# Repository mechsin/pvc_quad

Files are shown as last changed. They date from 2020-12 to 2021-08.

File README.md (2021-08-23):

# PVC Quadcopter

These are open SCAD files for a custom quadcopter that uses 1 inch PVC pipe and fittings for some of the construction. Original inspiration for the build was taken from this [instructables](https://www.instructables.com/The-Ultimate-PVC-Quadcopter/). My original design started off very similar to the build in the link however as can be seen from the pictures below my design has evolved quite a bit. The primary changes have been to augment or replace parts with 3d printed ones. At the moment the motor mounts and landing struts are 3d printed as a single piece. The I also have now added 3d printed mounts for the flight controller and power break out board. 

This is really just a personal project I don't intend to update this repo with full build notes. If would like to use any of the parts feel free to. 

The can all be printed with out supports. I use an Anet A8 to print them so you don't need a precision machine. I primary print in PLA or PLA+ my pieces break frequently but usually after a crash that I think would warrant it, I am not a great pilot :).

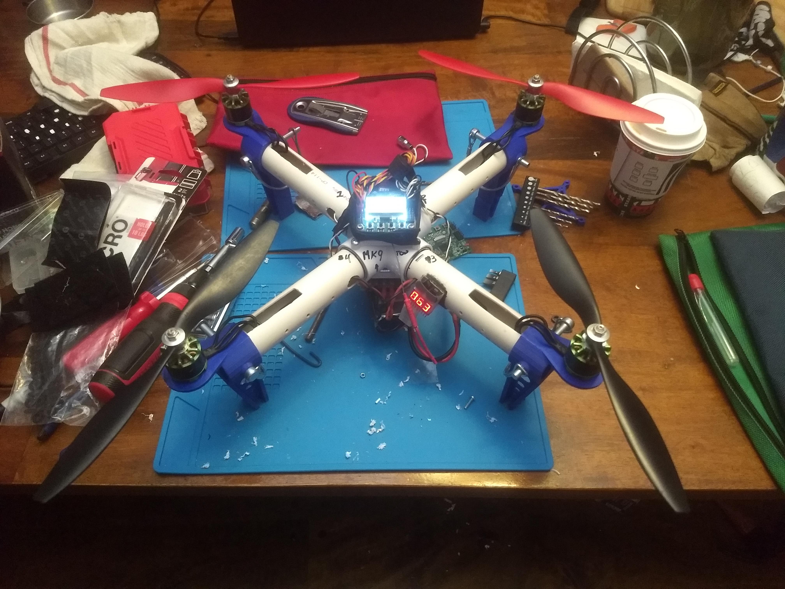
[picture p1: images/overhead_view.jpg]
Quad overview powered up and tools Quad over head view


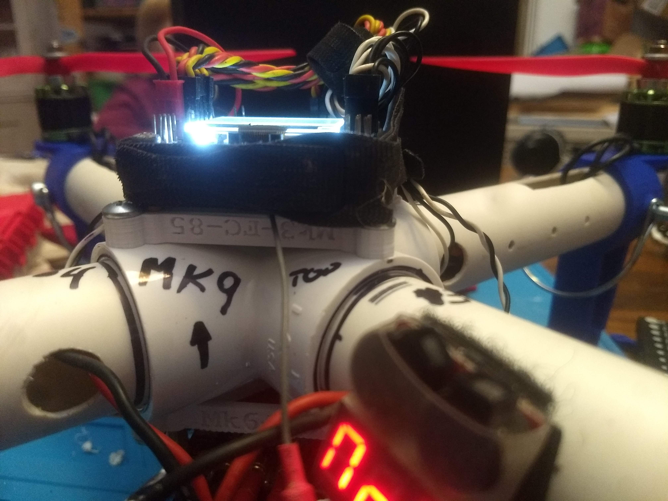
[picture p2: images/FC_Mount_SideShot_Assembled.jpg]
Flight controller mount up close FC Mount Side Shot


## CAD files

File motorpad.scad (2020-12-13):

use <quadparts.scad>;
use <pvcadapter.scad>;
use <landingstrut.scad>;

module pad_projection(baseWidth, padWidth, padLength, extra){

outerdiameter = padLength;
basewidth = baseWidth;

outerradius = outerdiameter / 2;
CS = sqrt (pow (outerradius + extra, 2) + pow (basewidth / 2, 2));
T = sqrt (pow (outerradius + extra, 2) + pow (basewidth / 2, 2) - pow(outerradius, 2));
phi = 180 - asin (outerradius / CS) - acos (basewidth / (2 * CS));

points =[[basewidth / 2, 0],
[basewidth / 2 + T * cos (phi), T * sin (phi)],
[-basewidth / 2 - T * cos (phi), T * sin (phi)],[-basewidth / 2, 0]];

resize([padWidth, padLength + extra])
union ()
{
polygon (points = points);
translate ([0, outerradius + extra])
circle (d = outerdiameter);
};
};

module padShaped(){
// This most outer difference removes all the extra material and shapes the piece as we want it
difference(){

// This initial difference on the pad makes the cut outs for the motor screw holes and makes the cutout
// for the motor cross pad that will eventually be added
difference(){
linear_extrude (height = height, center = false)
pad_projection(baseWidth, padWidth, padLength, extra=strech);

//Motor mount screw holes and cross pad
zMountCross = motorDepth;
translate([0, strech + padLength / 2, zMountCross])
rotate(-45)
mountCrossDiff(screwDiameter, mountDiameter, screwLength=height, motorDepth=motorDepth, extra=padThickness, centerHoleDiameter=centerHoleDiameter);
};


// Center cut out
// This creates the cylinder that makes the arc underneath the pad
cyWidth = padWidth + 5;
translate([0, totalLength, subHeight / 2])
union(){
resize([cyWidth, padLength * 2, subHeight])
rotate(90, v=[0, 0 ,1])
rotate(90, v=[1, 0, 0])
cylinder(cyWidth, r=padLength,center=true);
translate([-cyWidth / 2, -padLength, -subHeight / 2])
cube([cyWidth, padLength, subHeight / 2], center=false);
};

// Two cylinders to remove the material from the sides of the platform and create the I beam shape in the
// center
translate([padWidth / 2, totalLength, subHeight / 2])
resize([sideDiameter, totalLength, subHeight])
rotate(90, v=[1,0,0])
cylinder(h=totalLength, d=subHeight);

translate([-padWidth / 2, totalLength, subHeight / 2])
resize([sideDiameter, totalLength, subHeight])
rotate(90, v=[1,0,0])
cylinder(h=totalLength, d=subHeight);

// This is a cube that is used to remove excess material from the bottom of the model. There is
// a circular cut out in the top middle of it in order to leave the I beam shape
difference(){
translate([-padWidth / 2, 0, 0])
cube([padWidth, totalLength, height / 2]);

translate([0, totalLength, height / 2])
rotate(90,v=[1,0,0])
cylinder(h=totalLength, d=adapterInnerDiameter);
};
};
}

// Define all sizes having to do with the motor pad itself
//padLength = 45;
//padWidth = 53;
padLength = 38;
padWidth = 38;
padThickness = 4;
baseWidth = 20;
strech = 10;
totalLength = padLength + strech;
height = 42;
subHeight = height - padThickness;

// Define all measurements for the PVC adapter
adapterInnerDiameter = 34;
adapterOuterDiameter = 42;
adapterLength = strech + 20;
holeDepth = adapterLength;

//PVC adapter side mount holes
shScrewDiameter = 6.1;
shPadDiameter = 9;
shPadWidth = 1.5;
shChamferAngle = 45;

// Mark Text parameters
markText = "Mk5";
textHeight = 1.5;
markXTrans = -(baseWidth / 2 - 1);
markYTrans = -(adapterLength - strech - 1);


// These control the width of the I beam shape in that can be seen in the center of the
// hole for the PVC adapter
centerBarWidth = 5;
sideDiameter = padWidth - centerBarWidth;

// Measurements used to create the screw holes for mounting the motor.
screwDiameter = 3;
mountDiameter = 8;
screwLength = 12;
motorDepth = 3;
centerHoleDiameter = 8;

// Land strut measurements
strutLength = baseWidth;
strutWidthInitial = adapterLength;
strutWidthFinal = 15;
strutHeight = 70;




translate([0, 0, height])
rotate(180, v=[0,1,0])

union(){

padShaped();

// Add the motor mount cross pad for the screws
zMountCross = height - (screwLength - motorDepth);
translate([0, strech + padLength / 2, zMountCross])
rotate(-45)
mountCross(screwDiameter, mountDiameter, screwLength, motorDepth, extra=padThickness, centerHoleDiameter=centerHoleDiameter);



translate([0, strech, height / 2])
rotate(180, [0, 1, 0])
// Merge PVC Adapter and landing strut together
union() {
translate([-baseWidth / 2,-adapterLength,adapterOuterDiameter / 2])
landingStrut(strutLength, strutWidthInitial, strutWidthFinal, strutHeight, webCircles=true);
rotate(90, v=[1, 0, 0])
pvc_adapter(innerdiameter=adapterInnerDiameter,outerdiameter=adapterOuterDiameter,basewidth=baseWidth,extra=0,height=adapterLength, numberflats=2, sideholes=true, shpadwidth=shPadWidth, shpaddiameter=shPadDiameter, shscrewdiameter=shScrewDiameter, shchamferangle=shChamferAngle);
}


};

// Add Version text
//translate([markXTrans, markYTrans, height])
//linear_extrude(height=textHeight, center=false)
//text(markText, valign="bottom", halign="left", size=3);

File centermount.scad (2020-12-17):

module
hexagon (d, height)
// D is the distance between two oppisite vertices on the hexagon
// d is the distance between two parallel sides
{
   D = d * 2 / sqrt(3);
   t = D / 2;

   translate([0, 0, height / 2])
   union() {
   for (r =[0, 60, 120]) {
     rotate ([0, 0, r]) cube ([t, d, height], true);
   }
}
}


module
centerBoardMount(beamLength, beamWidth, beamHeight, hole2holeX, hole2holeY, boardDiameter, boardHoleDiameter, boardNutDiameter, boardNutDepth, mountDiameter, mountHoleDiameter, mountOffSet, braceOffset=0, braceWidth=0, centerHole=true)
{

// This translate list is use to create the holes for the board
// mount they are multiplid by diagonal distane between the
// board mounting holes as well as the diagonal for the mounting
// holes for the bracket it self
translateList = [
                     [1, 0, 0]
                    ,[0, 1, 0]
                    ,[-1, 0]
                    ,[0, -1, 0]
                  ];

diagonalBoard = sqrt(pow(hole2holeX, 2) + pow(hole2holeY, 2));
diagonalMount = beamLength - mountDiameter - 2 * mountOffset;
translateBoard = diagonalBoard/ 2 * translateList;
translateMount = concat(diagonalMount / 2 * translateList, [[0,0,0]]);

// Brace Dimensions
braceWidth = braceWidth ? braceWidth : beamWidth;

// After the part is constructed we flip it over and put it in the
// positive Z space. This is so the inserts for the nuts will be
// printed up.
translate([0,0, beamHeight])
rotate(180, v=[1, 0, 0])

// Subtract the holes in the mounts and the pocket for the nuts
difference() {

// Union all the arms, bracket and board mounts
union() {

   // Create the mounts for the board
   for (entry = translateBoard) {
      translate(entry)
      difference() {
         cylinder(d=boardDiameter, h=beamHeight);
      }
   }

  // Create the mounts for the bracket
  for (entry = translateMount) {
      translate(entry)
      cylinder(d=mountDiameter, h=beamHeight);
   }

   // Create on arm of the bracket
   translate([-beamWidth / 2, -beamLength / 2, 0])
   cube([beamWidth, beamLength, beamHeight]);

   // Create the other arm of the bracket
   rotate(-90)
   translate([-beamWidth / 2, -beamLength / 2, 0])
   cube([beamWidth, beamLength, beamHeight]);

   // Add braces if brace offset was provided
   if (braceOffset) {
      braceLength = sqrt(pow(braceOffset, 2) + pow(braceOffset, 2));
      bracePoints = [
                     [braceOffset, 0]
                     , [braceOffset + braceWidth / sin(45), 0]
                     , [0, braceOffset + braceWidth / sin(45)]
                     , [0, braceOffset]
                    ];
      for (rv = [0:90:270]) {
         rotate(rv, v=[0, 0, 1])
         linear_extrude(beamHeight)
         polygon(bracePoints);
      }
   }
};

// Create the holes for the board in the mounts and
// the pocket for the nuts
for (entry = translateBoard) {
      translate(entry)
      union() {
         cylinder(d=boardHoleDiameter, h=beamHeight, $fn=20);
         hexagon(boardNutDiameter, boardNutDepth);
      }

      }

// Create the holes for the bracke mount
for (entry = translateMount) {
      translate(entry)
      cylinder(d=mountHoleDiameter, h=beamHeight, $fn=20);
   }

};

}

//TEST

//// Board dimensions
//hole2holeX = 46;
//hole2holeY = 45;
//
//boardDiameter = 5 * 2 / sqrt(3) + 3;
//boardHoleDiameter = 2.8;
//boardNutDiameter = 5;
//boardNutDepth = 3.5;
//
//// Beam dimensions
//beamLength = 99;
//beamWidth = boardHoleDiameter;
//beamHeight = 7;
//
//// Mount hole dimensions
//mountDiameter = 8;
//mountHoleDiameter = 4.5;
//mountOffset = 2;
//
//// Brace
//braceOffset = sqrt(pow(hole2holeX, 2) + pow(hole2holeY, 2)) / 2;
//
//
//centerBoardMount(beamLength, beamWidth, beamHeight, hole2holeX, hole2holeY, boardDiameter, boardHoleDiameter, boardNutDiameter, boardNutDepth, mountDiameter, mountHoleDiameter, mountOffset, braceOffset=braceOffset, centerHole=true);

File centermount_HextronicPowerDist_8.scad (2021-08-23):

include<centermount.scad>


// Dimensions for the PCB
// X and Y offsets for the mounting holes for the PCB
offsetX = 45;
offsetY = 44;

boardDiameter = 5 * 2 / sqrt(3) + 3;
boardHoleDiameter = 2.8;
boardNutDiameter = 5.2;
boardNutDepth = 3.5;

// Beam Dimensions

beamLength = 85;
beamWidth = boardHoleDiameter;
beamHeight = 7;

// Mount hole dimensions
mountDiameter = 8;
mountHoleDiameter = 4.5;
mountOffset = 0;

// Brace
braceOffset = sqrt(pow(offsetX, 2) + pow(offsetY, 2)) / 2;

difference(){

centerBoardMount(beamLength, beamWidth, beamHeight, offsetX, offsetY, boardDiameter, boardHoleDiameter, boardNutDiameter, boardNutDepth, mountDiameter, mountHoleDiameter, mountOffset, braceOffset=braceOffset, centerHole=true);

// Part Marking
letterDepth = 1;

r = sqrt(pow(braceOffset, 2) + pow(braceOffset, 2)) / 2 + beamWidth - letterDepth;
translate([r * cos(45), r * sin(45), 1])
rotate(135, v=[0,0,1])
rotate(90, v=[1,0,0])
linear_extrude(letterDepth)
text("Mk6-HX-85", size=5, font="Nimbus Mono PS:style=Bold", halign="center");
}

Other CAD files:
centermount_KK_2.1.5_FC.scad
centermount_LantianRCPowerDist.scad
landingstrut.scad
pvcadapter.scad
quadparts.scad

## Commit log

2020-12-13 Add mount drawings
    I am going back and recrating this repo so I can track the
    evolution of this mount
    [motorpad.scad, pvcadapter.scad, quadparts.scad]
2020-12-13 Mk 2 update
    Major update here is to change the motor pad itself from a
    square to a circular shape eliminating a lot of material and
    reducing print time and weight
    [motorpad.scad]
2020-12-13 Add side mount holes
    I am adding side mount holes so I don't have to drill holes
    after the fact.
    [motorpad.scad]
2020-12-13 Increase diameter of motor cross pad
    I am increasing the diameter of the motor cross pad by a few mm.
    I am doing this because I have had two crashes where two different
    mounts have broken in strikingly similar ways. My theory is that
    the pad is flexing and one of the screw heads is making contact with
    the cutout wall. When this happens the screw doesn't flex and causes
    the mount to crack.
    [motorpad.scad]
2020-12-13 Mark 6 improvements
    There were several improvements in the iteration
    Most obvious is that I added a landing strut to the bottom of the
    motor mount. This is in preperation for a full redesign of the
    quadcopter that will move the landing gear out to the ends of the
    arms.
    Next I added a center hole to the motor cross. My previous motors
    didn't have any of there center spindle protruding however I
    picked up some different motors recently that do so I need a hole
    in the center so that the spindle doesn't rub.
    One other minor update is that I made changes to the pvc adapter
    module so now it can have a setable number of flat sides. I need
    to update the arguments to reflect this change.
    Addition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
    [landingStrut.scad, motorpad.scad]
2020-12-13 Change name of landing strut file to all lower case
    [landingstrut.scad]
2020-12-13 Update file names and comment out test
    I am updating the names of the pvc adapter and landing strut files
    to have no spaces keeping with the other file names.
    I am also commenting out the test part at the bottom of the
    landing strut file.
    [landingstrut.scad, motorpad.scad]
2020-12-13 Increase the size of the side hole for pins
    On the Mk6 parts the side hole is a bit small for the pins I have
    so I am increasing the size by 0.1 mm. To see if this fixes the
    issue. I don't want to cause extra stress at those layer lines.
    [motorpad.scad]
2020-12-13 Add center mount circuit board models
    I am adding three more models here late. The center mount file
    is the original with the other files basically copying that file
    with slightly different dimenisons for there boards.
    [centermount.scad, centermount_HextronicPowerDist_8.scad, centermount_KK_2.1.5_FC.scad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]
2020-12-13 Convert centermount into module
    I have converted the center mount sub part into a module that way
    the various PCBs that I want to use it with can each have there
    own file without having to update them individually when I make
    a change.
    [centermount.scad]
2020-12-13 Convert HextronicPowerDist mount to module
    In the previous commit I made the center mount a module now I am
    converting the Hextronic to use that module.
    [centermount_HextronicPowerDist_8.scad]
2020-12-14 Fix issue with hex construction height
    In trying to make the pocket for the nut deeper on the bracket I
    found that small changes weren't having the desired result upon
    looking at the model I discovered that the reason was that half
    the length of the hexagon is below the z plane to start with
    meaning every dimension change I made was being cut in half. I
    am fixing this in the hex function by translating the part up
    by half the height before exiting the function.
    I also found I wasn't unioning the different boxes so they were
    just being group in my models by accident.
    [centermount.scad]
2020-12-17 Add max removal base on right tangent trapizoid
    Currently the circles in the web of the strut are just created
    based on a simple algorithm that determines the max size base
    on some other parameters. I am converting this method to one
    that uses the properties of a right tangential trapizoid in order
    to find the size of each trapizoid so that a circle that is tangent
    to all sides can be created maximizing the amount of material
    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
    [landingstrut.scad]
2020-12-17 Add option to have square box braces centermount
    I am adding and option to allow the user to add box braces to the
    center mount model. This will stiff the arms ensuring there isn't
    any deformation when mounting but it will also possibly provide a
    location to mount the batter with velcro straps on the bottom.
    [centermount.scad]
2020-12-18 Update Hextronic model to use center braces
    I want to try and use these center braces to mount the
    battery.
    [centermount_HextronicPowerDist_8.scad]
2020-12-18 Convert KK FC mount to use center mount module
    Now the the center mount model is a module I am converting
    the KK flight controller braket over to using it.
    [centermount_KK_2.1.5_FC.scad]
2020-12-18 Add model version markings to the KK FC part
    I am adding version markings to the center mount KK flight
    controller model. This will make it easier to keep track of
    which version of the model I am using, hopefullly.
    [centermount_KK_2.1.5_FC.scad]
2020-12-18 Add version markings to Hextronic center mount
    I am adding the same type of verison markings to the
    Hextronic center mount as the KK flight controller
    board.
    [centermount_HextronicPowerDist_8.scad]
2021-08-23 Adjust mount parameters update text
    I have a smaller PVC 4 ways at this time so I am adjusting
    the length and hole parameters for the power distribution
    and flight controller boards.
    I am also adding some identifying text so I can tell one mount
    from the other.
    [centermount_HextronicPowerDist_8.scad, centermount_KK_2.1.5_FC.scad]
